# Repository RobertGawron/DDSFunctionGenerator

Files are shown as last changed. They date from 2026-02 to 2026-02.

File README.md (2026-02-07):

# 6MHz DDS Function Generator

**This project is unfinished.**

 

## Summary

A function generator is a laboratory instrument used to generate various electrical waveforms. This project utilizes DDS  [DDS (direct digital synthesis)](https://en.wikipedia.org/wiki/Direct_digital_synthesis), a technique that allows the creation of arbitrary waveforms from a single base frequency.

## Current Version

The current version of the PCB uses components with 0402 (or similar) footprints. Use of these components wasn’t the best choice - they're too difficult to solder, and there was no need to minimize the board size. The next version of the PCB will switch to 0805 components for easier assembly.

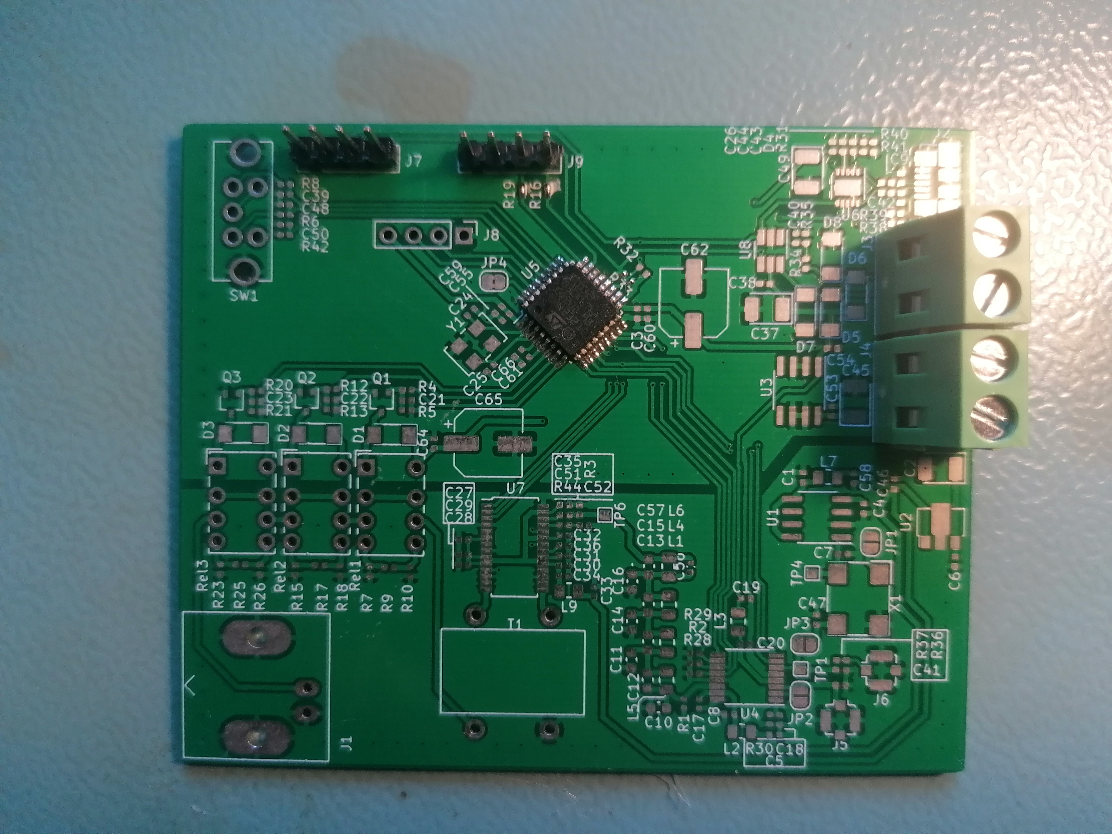
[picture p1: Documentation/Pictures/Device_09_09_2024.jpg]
Photo of the assembled PCB


## System Architecture

System Architecture

Tools: PlantUML

## Hardware

Tools: KiCad (for PCB design).

## Software

Tools:
* **Business Logic:** Written in Forth, a stack-based programming language designed for embedded systems and control applications.
* **Drivers:** Developed in C++17.
* **Hardware Abstraction Layer (HAL):** Auto-generated using CubeMX, a tool from STMicroelectronics.

## Simulation

This project includes an LCD for user interaction. To simplify the creation of the layout, a simulation environment has been developed. 

This simulation combines the following:
* **UI:** Built using PyQt for rendering the LCD layout and facilitating user interaction.
* **Business Logic:** Reuses the core firmware logic directly from the hardware codebase.
* HAL and Driver Mocks: Created in C++.

[More Info](./Simulation/FirmwarePCSimulator/README.md)

## Enclosure

The device's enclosure is designed using **OpenSCAD**, a script-based 3D CAD modeler that allows precise and parametric design.

[More Info](./Mechanic/MechanicOverview/README.md)

## Devops

Repetitive setup tasks are best left to automation, which is why the development environment is managed with Docker. This approach eliminates the need to deal with outdated installation lists or READMEs—just run the container, and everything is ready to go.

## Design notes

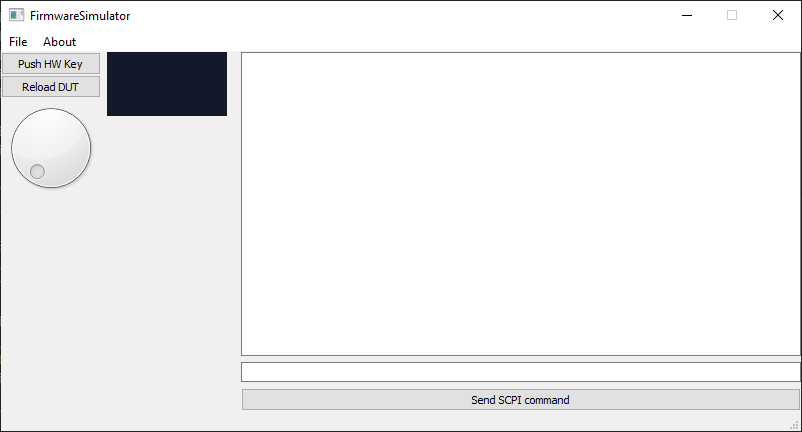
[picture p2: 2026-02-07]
Documentation/Pictures/PCSimulation_20_10_2020.png

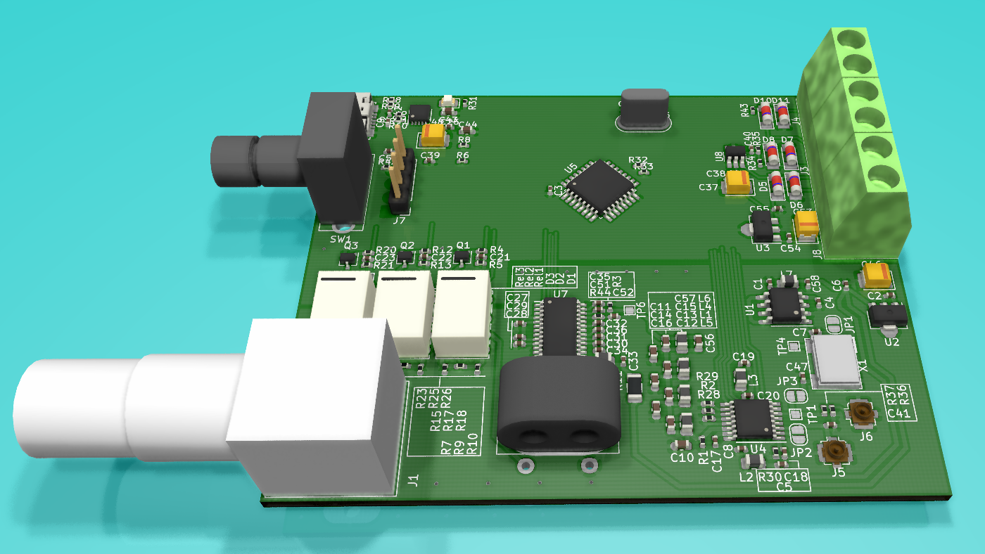
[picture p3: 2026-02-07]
Documentation/Pictures/render_08_12_2019.png

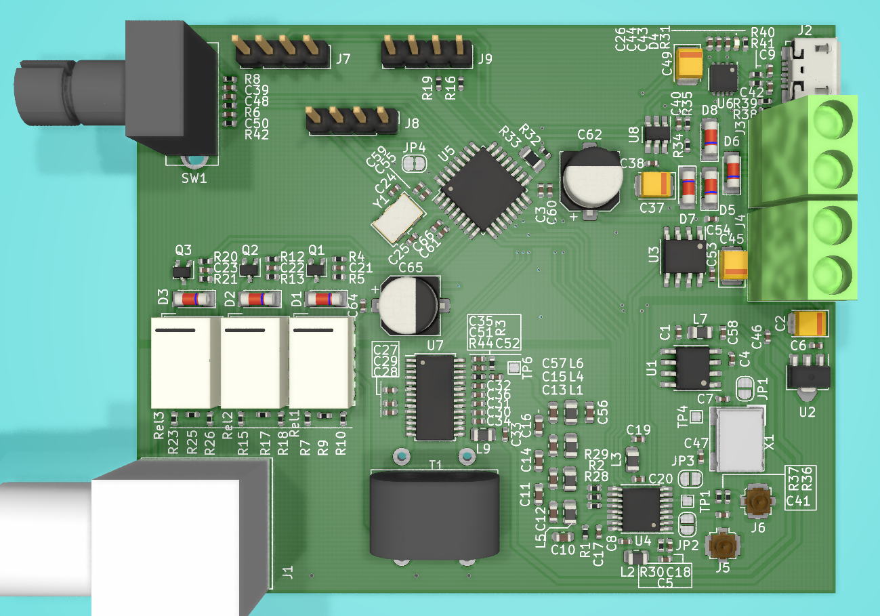
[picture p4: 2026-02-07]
Documentation/Pictures/render_28_12_2019.png

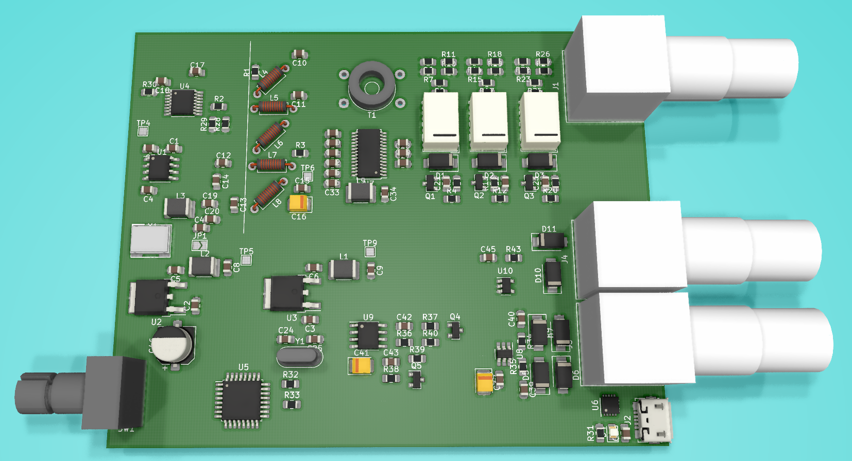
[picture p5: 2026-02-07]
Documentation/Pictures/render_01_11_2019.png

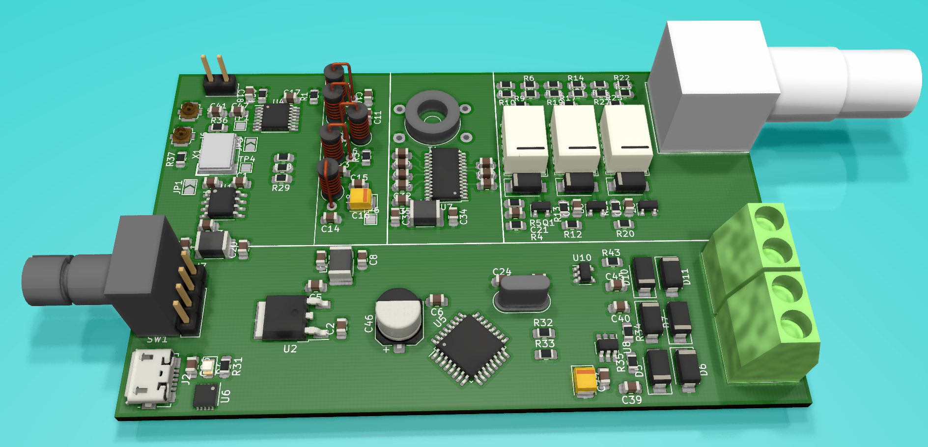
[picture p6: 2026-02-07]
Documentation/Pictures/render_03_11_2019.png

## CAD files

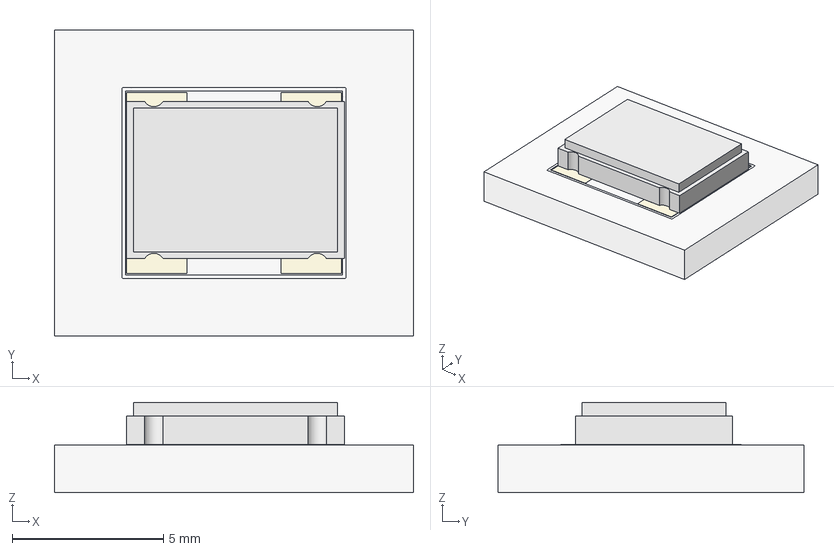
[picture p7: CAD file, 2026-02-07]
Mechanic/KiCADModels/FreeCAD/LF_SPXO018035.FCStd
11.9 x 10.1 x 2.99 mm
FrontSilk
TopPads
Pcb

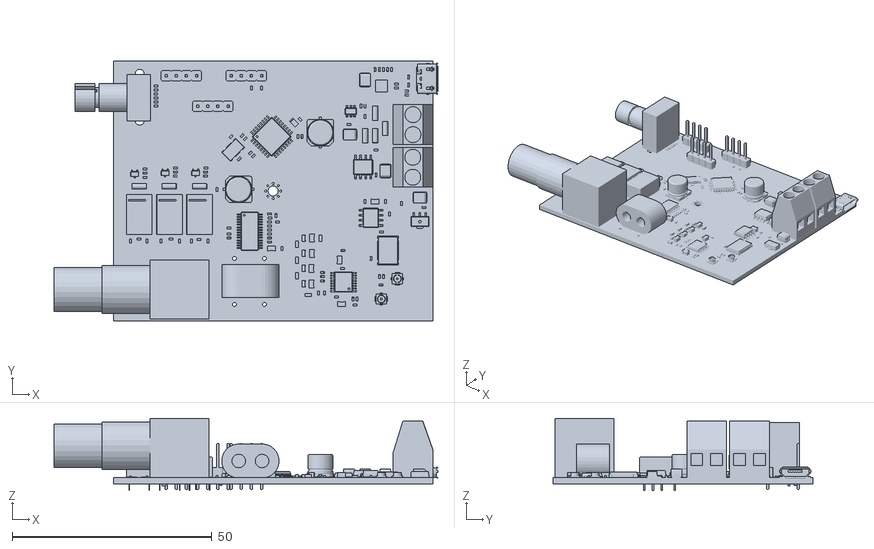
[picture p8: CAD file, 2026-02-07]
Mechanic/MechanicOverview/PCB.stl
96.1 x 65.0 x 18.1

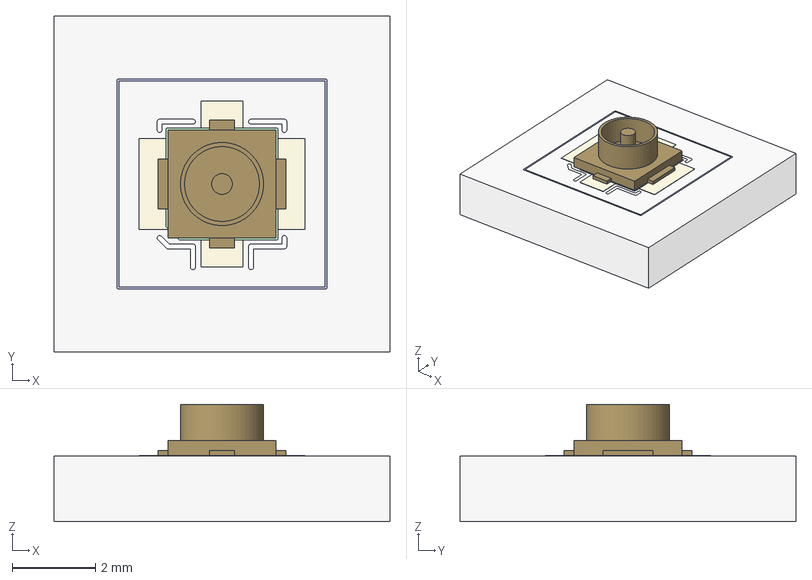
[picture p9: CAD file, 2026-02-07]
Mechanic/KiCADModels/FreeCAD/MOLEX_73412-0110.FCStd
8.08 x 8.08 x 2.82 mm
FCrtYd
FFab
FrontSilk
TopPads
Pcb
LinearExtrude

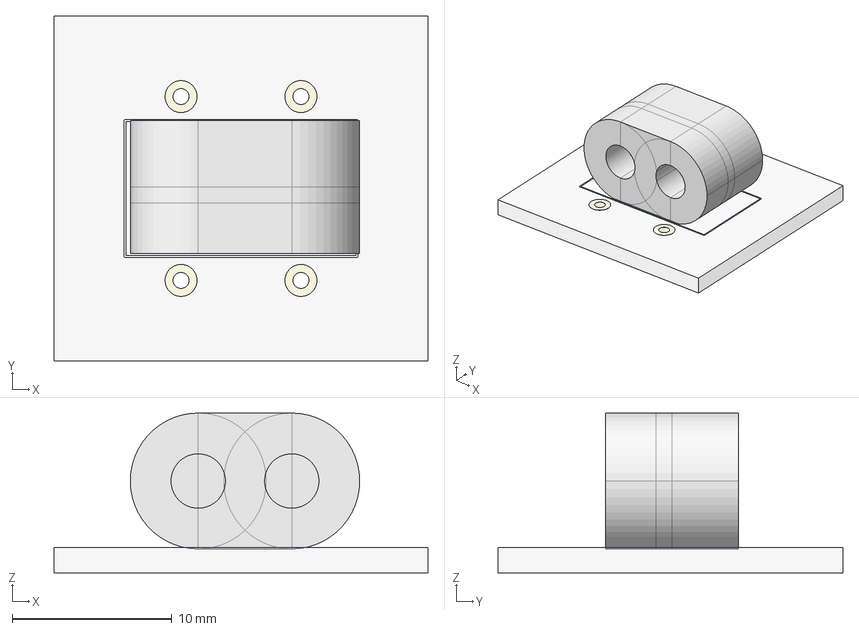
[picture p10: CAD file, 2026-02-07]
Mechanic/KiCADModels/FreeCAD/Transformer_B62152_8.3.FCStd
23.4 x 21.6 x 10.0 mm
FrontSilk
TopPads
BotPads
PTHs
Pcb

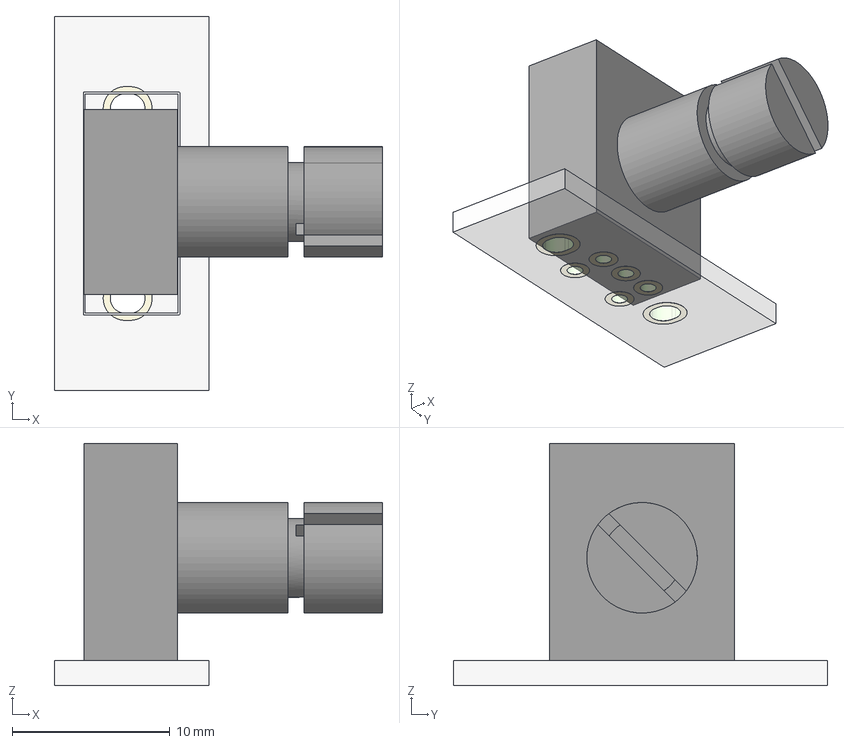
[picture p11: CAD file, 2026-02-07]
Mechanic/KiCADModels/FreeCAD/EN11-VNB1BQ15.FCStd
20.8 x 23.7 x 15.3 mm
FrontSilk
TopPads
BotPads
PTHs
Pcb
Matrix_Union

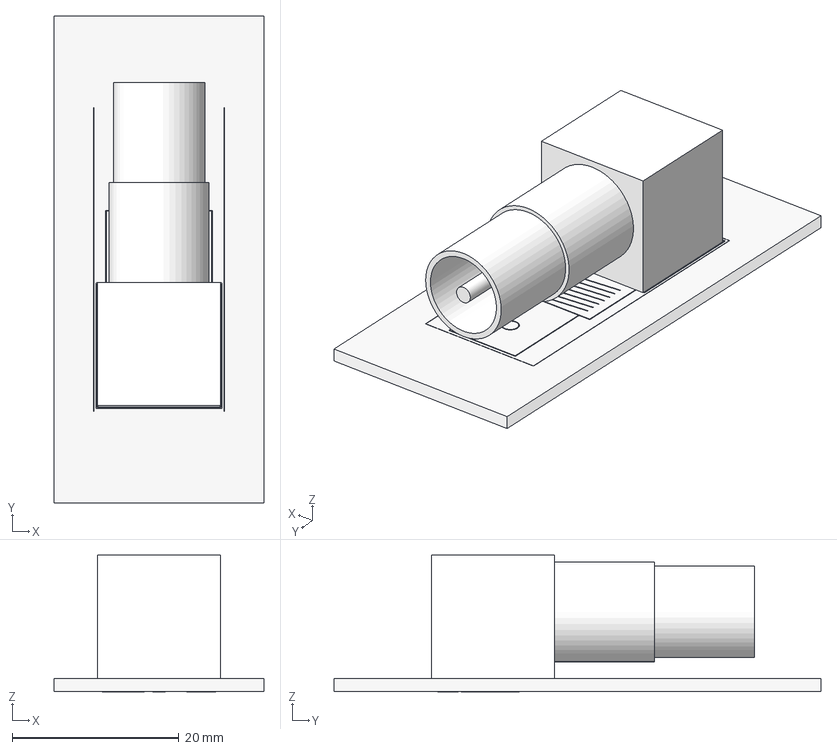
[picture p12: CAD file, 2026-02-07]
Mechanic/KiCADModels/FreeCAD/BNC_Amphenol_B6252HB-NPP3G-50_Horizontal.FCStd
25.2 x 58.5 x 16.4 mm
FCrtYd
FFab
FrontSilk
TopPads
BotPads
PTHs
Pcb

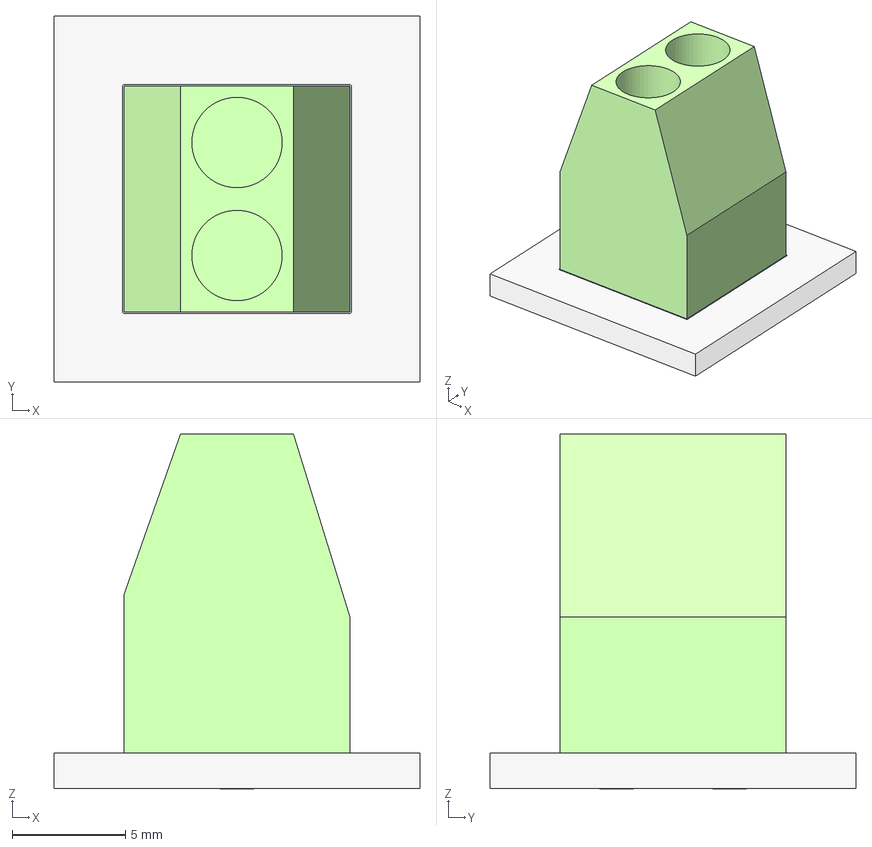
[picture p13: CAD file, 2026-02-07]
Mechanic/KiCADModels/FreeCAD/DG128-5.0-02P-14-00A.FCStd
16.2 x 16.2 x 15.7 mm
FrontSilk
TopPads
BotPads
PTHs
Pcb

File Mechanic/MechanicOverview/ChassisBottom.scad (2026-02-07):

// This is model of bottom chassis.

module ChassisBottom_FrontPanel(Height)
{
    translate([-PCB_X/2 - CHASSIS_THICKNESS-COMPONENT_TOLERANCE,
                -PCB_Y/2,
                Height])
    {
        GenericFrontPanel();
    }
}

module ChassisBottom_SupportAroundPCB()
{
    linear_extrude(height = 2*CHASSIS_THICKNESS+PCB_Z_OFFSET, convexity = 10, twist = 0)
    {
        square([PCB_X+2*COMPONENT_TOLERANCE, CHASSIS_THICKNESS]);
    }
}

module ChassisBottom_SupportsAroundPCB()
{
    translate([-PCB_X/2 -COMPONENT_TOLERANCE,
                -PCB_Y/2-CHASSIS_THICKNESS-COMPONENT_TOLERANCE,
                0])
    {
        ChassisBottom_SupportAroundPCB();
    }

    translate([-PCB_X/2 - COMPONENT_TOLERANCE,
                PCB_Y/2+COMPONENT_TOLERANCE,
                0])
    {
        ChassisBottom_SupportAroundPCB();
    }
}

module ChassisBottom_PCBMountingHole()
{
    translate([0,
                0,
                CHASSIS_THICKNESS])
    {
        GenericChassis_InsertNutSocket(PCB_Z_OFFSET, false);
    }
}

module ChassisBottom_PCBBottomHolder()
{
    PCBBottomHolderThickness = 2;

    linear_extrude(height = PCB_Z_OFFSET, convexity = 10, twist = 0)
    {
        square([PCBBottomHolderThickness, PCB_Y]);
    }
}

module ChassisBottom_PCBBottomHolders()
{
    translate([-PCB_X/2,
                -PCB_Y/2,
                CHASSIS_THICKNESS])
    {
        ChassisBottom_PCBBottomHolder();
    }

    translate([PCB_X/2-1,
                -PCB_Y/2,
                CHASSIS_THICKNESS])
    {
        ChassisBottom_PCBBottomHolder();
    }
}

module ChassisBottom(Height)
{
    difference()
    {
        union()
        {
            GenericChassis(Height);
            ChassisBottom_FrontPanel(Height);
            ChassisBottom_SupportsAroundPCB();
            ChassisBottom_PCBMountingHole();
            ChassisBottom_PCBBottomHolders();

            InsertNutSockets(Height, false);
        }

        // add mounting for top and bottom chassis
        InsertNutSockets(Height, true);

                // add hole for USB socket
        TopHassisUsbYOffset = -2.4; // TODO parametrize it
        translate([PCB_X/2 + COMPONENT_TOLERANCE, 
                    USB_Y,
                    Height + TopHassisUsbYOffset])
        {
            rotate([90,0,90])
            {
                USBConnector();
            }
        }
    }
}

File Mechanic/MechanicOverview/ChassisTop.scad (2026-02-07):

// This is model of top chassis.

// below values are taken from KiCad model

SCREW_CONNECTOR_DX = 10 + COMPONENT_TOLERANCE;
SCREW_CONNECTOR_Y = 1 - COMPONENT_TOLERANCE;
SCREW_CONNECTOR_DY = 20.668 + 2*COMPONENT_TOLERANCE;

AdcPowerSupplyYOffset = PCB_X/2
                        - SCREW_CONNECTOR_DX
                        + CHASSIS_THICKNESS
                        - COMPONENT_TOLERANCE;

module ChassisTop_WallsAroundADCAndPowerSupplySocket(Height)
{
    linear_extrude(height = Height, convexity = 10, twist = 0)
    {
        translate([AdcPowerSupplyYOffset,
                    -SCREW_CONNECTOR_DY - SCREW_CONNECTOR_Y - CHASSIS_THICKNESS,
                    0])
        {
            square([SCREW_CONNECTOR_DX + COMPONENT_TOLERANCE, CHASSIS_THICKNESS]);
        }

        translate([AdcPowerSupplyYOffset,
                    -SCREW_CONNECTOR_DY - SCREW_CONNECTOR_Y + SCREW_CONNECTOR_DY,
                    0])
        {
            square([SCREW_CONNECTOR_DX + COMPONENT_TOLERANCE, CHASSIS_THICKNESS]);
        }

        translate([AdcPowerSupplyYOffset,
                    -SCREW_CONNECTOR_DY - SCREW_CONNECTOR_Y,
                    0])
        {
            square([CHASSIS_THICKNESS, SCREW_CONNECTOR_DY + CHASSIS_THICKNESS]);
        }
    }
}

module ChassisTop_SupportFrontPanel()
{
    translate([-PCB_X/2 -COMPONENT_TOLERANCE,
               -PCB_Y/2,
                CHASSIS_THICKNESS])
    {
        linear_extrude(height = CHASSIS_THICKNESS, convexity = 10, twist = 0)
        {
            square([CHASSIS_THICKNESS, PCB_Y]);
        }
    }

}

module ChassisTop_DebugPanelMountingScrewSupport()
{

    DebugPanelSupportSize = 10;

    translate([-PCB_X/2+DEBUG_CONNECTOR_X+DEBUG_CONNECTOR_DX/2,
            -PCB_Y/2+DEBUG_CONNECTOR_DY/2+COMPONENT_TOLERANCE,
            0])
    {
        difference()
        {
            union()
            {
                translate([0,DebugPanelSupportSize/2,0])
                {
                    linear_extrude(height = CHASSIS_THICKNESS+INSERT_NUT_LENGTH, convexity = 10, twist = 0)
                    {
                        square([INSERT_NUT_HOLDER_DIAMETER, DebugPanelSupportSize], center=true);
                    }
                }
                GenericChassis_InsertNutSocket(CHASSIS_THICKNESS+INSERT_NUT_LENGTH, false);
            }

            // add hole for debug socket screw
            linear_extrude(height = CHASSIS_THICKNESS+INSERT_NUT_LENGTH, convexity = 10, twist = 0)
            {
                circle(r=INSERT_NUT_RADIUS);
            }
        }
    }
}

module Chassis3DTop(Height)
{
    difference()
    {
        union()
        {
            difference()
            {
                GenericChassis(Height);
                GenericDebugPanel(Height);
            }

            ChassisTop_DebugPanelMountingScrewSupport();
        }

        // add hole for ADC and power supply socket
        translate([AdcPowerSupplyYOffset,
                    -SCREW_CONNECTOR_DY - SCREW_CONNECTOR_Y,
                    0])
        {
            linear_extrude(height = Height, convexity = 10, twist = 0)
            {
                square([SCREW_CONNECTOR_DX + CHASSIS_THICKNESS, SCREW_CONNECTOR_DY]);
            }
        }

        // add hole for front pannel
        translate([-PCB_X/2 - CHASSIS_THICKNESS-COMPONENT_TOLERANCE,
                   -PCB_Y/2,
                    CHASSIS_THICKNESS])
        {
            GenericFrontPanel();
        }

        // add hole for USB socket
        TopHassisUsbYOffset = -0.85; // TODO parametrize it
        translate([PCB_X/2 + COMPONENT_TOLERANCE,
                    -USB_Y-USB_LENGTH,
                    Height + TopHassisUsbYOffset])
        {
            rotate([90,0,90])
            {
                USBConnector();
            }
        }
    }

    ChassisTop_WallsAroundADCAndPowerSupplySocket(Height);
    ChassisTop_SupportFrontPanel();

    // add nounting screws
    InsertNutSockets(Height, false);




    
}

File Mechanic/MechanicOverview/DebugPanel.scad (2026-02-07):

// This is model panel for UART and MCU sockets, it will be taken out for debugging and development.

module GenericDebugPanel(Height)
{
    translate([-PCB_X/2+DEBUG_CONNECTOR_X,
                ,-PCB_Y/2
                    + COMPONENT_TOLERANCE
                    - 2*CHASSIS_THICKNESS // TODO this is wrong
                    - DEBUG_CONNECTOR_DY/2
                    + CHASSIS_CORNER_DIAMETER,
                0])
    {
        linear_extrude(height = Height, convexity = 10, twist = 0)
        {
            square([DEBUG_CONNECTOR_DX, DEBUG_CONNECTOR_DY]);
        }
    }
}

module DebugPanel(Height)
{
    difference()
    {
        GenericChassis(Height);

        difference()
        {
            GenericChassis(Height);
            GenericDebugPanel(Height);
        }
    }
}

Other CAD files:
Mechanic/MechanicOverview/GenericChassis.scad
Mechanic/KiCADModels/FreeCAD/MOLEX_73412-0110.scad
Mechanic/KiCADModels/OpenSCAD/BNC_Amphenol_B6252HB-NPP3G-50_Horizontal.scad
Mechanic/KiCADModels/OpenSCAD/DG128-5.0-02P-14-00A.scad
Mechanic/KiCADModels/OpenSCAD/EN11-VNB1BQ15.scad
Mechanic/KiCADModels/OpenSCAD/LF_SPXO018035.scad
Mechanic/KiCADModels/OpenSCAD/Transformer_B62152_8.3.scad
Mechanic/MechanicOverview/GenericFrontPanel.scad
Mechanic/MechanicOverview/MechanicOverview.scad
Mechanic/MechanicOverview/USBConnector.scad

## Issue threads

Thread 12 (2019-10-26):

Update README.md for render of PCB.

RobertGawron, 2019-10-26:

RobertGawron, 2019-11-01:
Fixed by 70bd080a7f343182590361790dcc85e7a82861be

Closed 2019-11-01.

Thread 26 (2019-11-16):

Check order of pin 2 and 3 on the USB socket

RobertGawron, 2019-11-16:
What is the order on the socked I have? Needed to avoid rework after assembly.

RobertGawron, 2021-07-17:
done

Closed 2021-07-17.

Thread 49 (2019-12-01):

Check bottom/top layer correctness before ordering PCB

RobertGawron, 2019-12-01:

RobertGawron, 2021-07-17:
done

Closed 2021-07-17.

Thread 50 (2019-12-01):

Add 3D model of enclosure

RobertGawron, 2019-12-01:

RobertGawron, 2020-12-08:
Missing parts :
- PCB support,
- holes to mount PCB
- fix screw support for top part
- add hole for BNC, encoder and LCD
- finish debug connector
- add USB slot

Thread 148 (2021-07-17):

Fix USB footprint

RobertGawron, 2021-07-17:

RobertGawron, 2021-10-02:
USB from Raspberry will be used.

Closed 2021-10-02.

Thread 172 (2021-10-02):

Replace fancy encoder by 4 buttons

RobertGawron, 2021-10-02:

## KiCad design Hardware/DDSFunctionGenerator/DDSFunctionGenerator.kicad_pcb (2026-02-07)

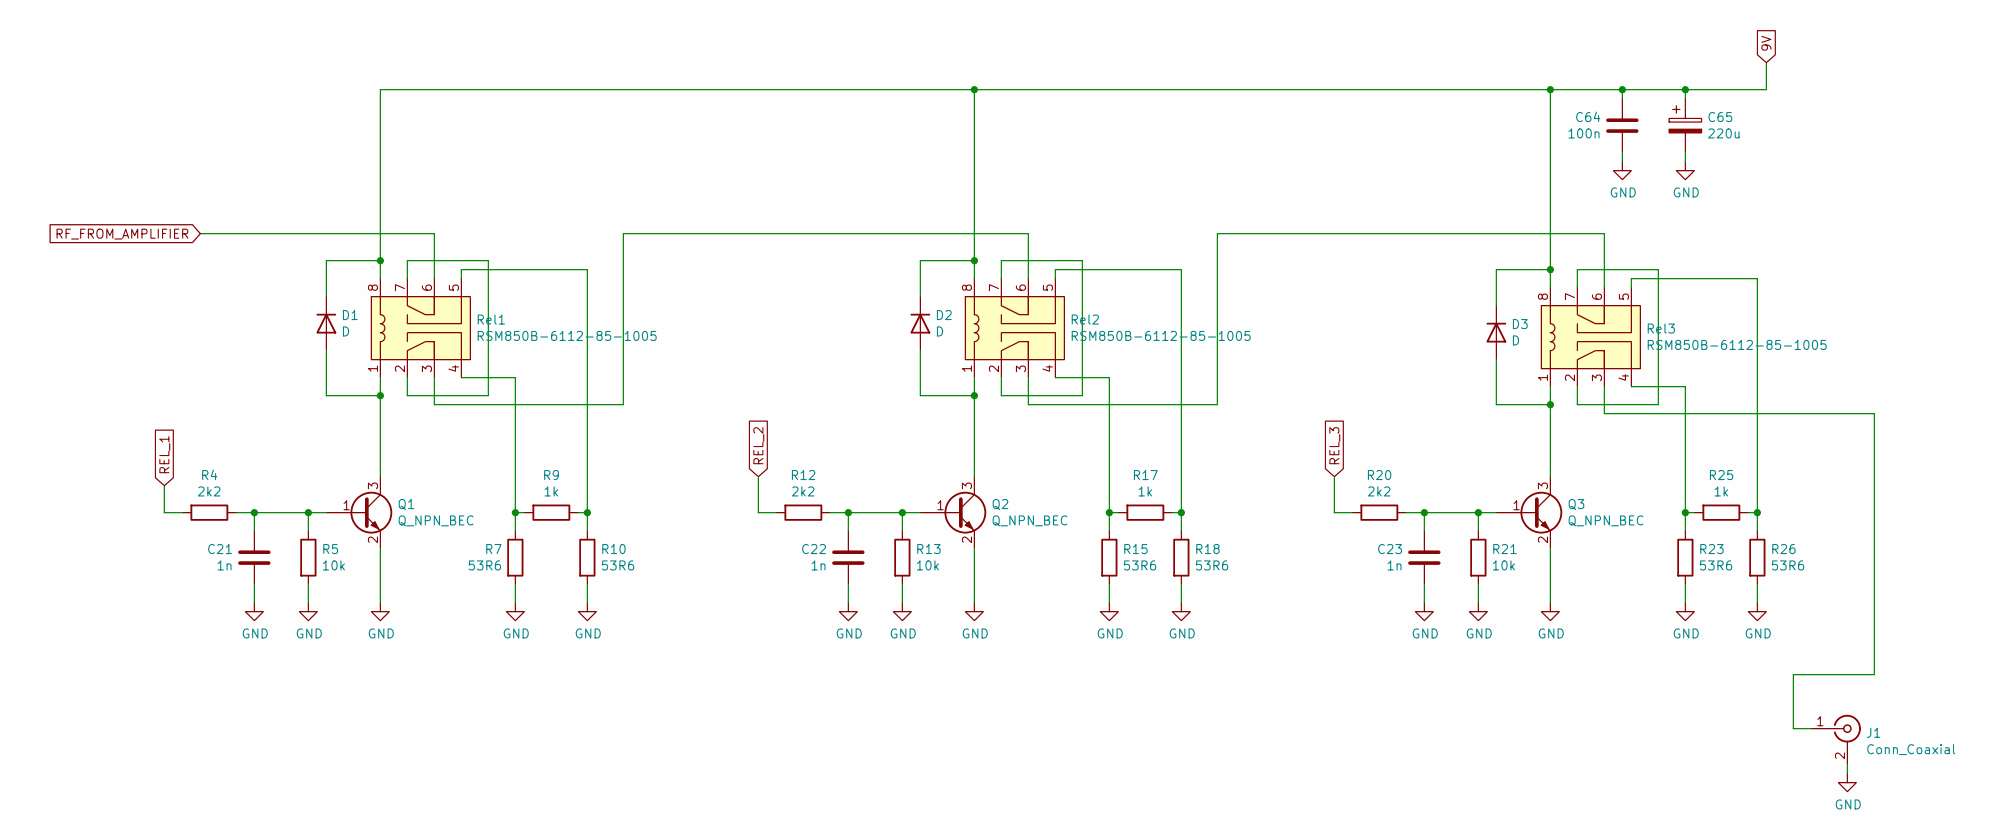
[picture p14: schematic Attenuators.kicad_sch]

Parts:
C21, C22, C23: 1n; C_0402_1005Metric
C64: 100n; C_0402_1005Metric
C65: 220u; CP_Elec_6.3x5.8
D1, D2, D3: D; D_MiniMELF
J1: Conn_Coaxial; BNC_Amphenol_B6252HB-NPP3G-50_Horizontal
Q1, Q2, Q3: Q_NPN_BEC; SOT-323_SC-70
R4, R12, R20: 2k2; R_0402_1005Metric
R5, R13, R21: 10k; R_0402_1005Metric
R7, R10, R15, R18, R23, R26: 53R6; R_0402_1005Metric
R9, R17, R25: 1k; R_0402_1005Metric
Rel1, Rel2, Rel3: RSM850B-6112-85-1005; Relay_DPDT_Omron_G6K-2P-Y

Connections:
9V: C64.1, C65.1, D1.1 (K), D2.1 (K), D3.1 (K), Rel1.8, Rel2.8, Rel3.8; also elsewhere on the board
GND: C21.2, C22.2, C23.2, C64.2, C65.2, J1.2 (Ext), Q1.2 (E), Q2.2 (E), Q3.2 (E), R5.2, R7.2, R10.2, R13.2, R15.2, R18.2, R21.2, R23.2, R26.2; also elsewhere on the board
unnamed: C21.1, Q1.1 (B), R4.1, R5.1
unnamed: C22.1, Q2.1 (B), R12.1, R13.1
unnamed: C23.1, Q3.1 (B), R20.1, R21.1
unnamed: D1.2 (A), Q1.3 (C), Rel1.1
unnamed: D2.2 (A), Q2.3 (C), Rel2.1
unnamed: D3.2 (A), Q3.3 (C), Rel3.1
unnamed: J1.1 (In), Rel3.3
unnamed: R7.1, R9.2, Rel1.4
unnamed: R9.1, R10.1, Rel1.5
unnamed: R15.1, R17.2, Rel2.4
unnamed: R17.1, R18.1, Rel2.5
unnamed: R23.1, R25.2, Rel3.4
unnamed: R25.1, R26.1, Rel3.5
unnamed: Rel1.2, Rel1.7
unnamed: Rel1.3, Rel2.6
unnamed: Rel2.2, Rel2.7
unnamed: Rel2.3, Rel3.6
unnamed: Rel3.2, Rel3.7
REL_1: R4.2; also elsewhere on the board
REL_2: R12.2; also elsewhere on the board
REL_3: R20.2; also elsewhere on the board
RF_FROM_AMPLIFIER: Rel1.6; also elsewhere on the board

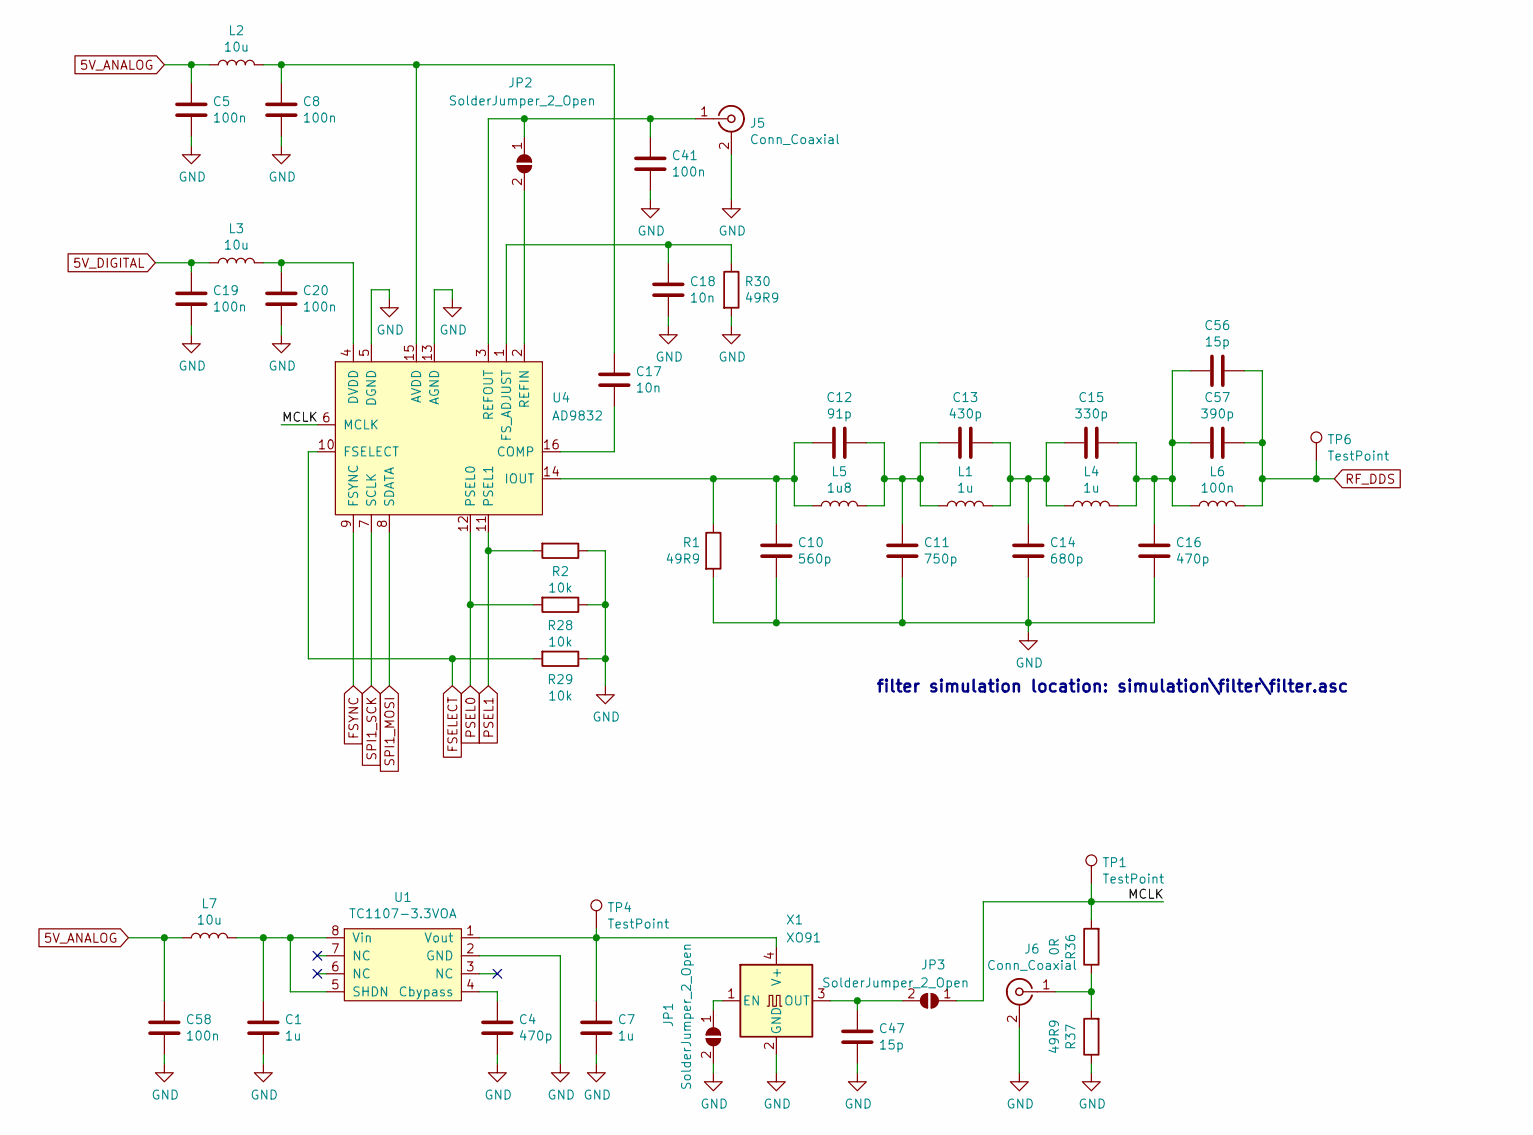
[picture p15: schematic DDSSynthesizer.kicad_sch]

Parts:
C1, C7: 1u; C_0402_1005Metric
C4: 470p; C_0402_1005Metric
C5, C8, C19, C20, C41, C58: 100n; C_0402_1005Metric
C10: 560p; C_0603_1608Metric
C11: 750p; C_0603_1608Metric
C12: 91p; C_0603_1608Metric
C13: 430p; C_0603_1608Metric
C14: 680p; C_0603_1608Metric
C15: 330p; C_0603_1608Metric
C16: 470p; C_0603_1608Metric
C17, C18: 10n; C_0402_1005Metric
C47, C56: 15p; C_0402_1005Metric
C57: 390p; C_0603_1608Metric
J5, J6: Conn_Coaxial; U.FL_Molex_MCRF_73412-0110_Vertical
JP1, JP2, JP3: SolderJumper_2_Open; SolderJumper-2_P1.3mm_Open_RoundedPad1.0x1.5mm
L1, L4: 1u; L_0805_2012Metric
L2, L3, L7: 10u; L_0805_2012Metric
L5: 1u8; L_0805_2012Metric
L6: 100n; L_0805_2012Metric
R1, R30, R37: 49R9; R_0402_1005Metric
R2, R28, R29: 10k; R_0402_1005Metric
R36: 0R; R_0402_1005Metric
TP1, TP4, TP6: TestPoint; TestPoint_Pad_1.0x1.0mm
U1: TC1107-3.3VOA; SOIC-8_3.9x4.9mm_P1.27mm
U4: AD9832; TSSOP-16_4.4x5mm_P0.65mm
X1: XO91; LF_SPXO018035

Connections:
5V_ANALOG: C5.1, C58.1, L2.1, L7.1; also elsewhere on the board
5V_DIGITAL: C19.1, L3.1; also elsewhere on the board
/DDSSynthesizer/MCLK: JP3.1 (A), R36.2, TP1.1, U4.6 (MCLK)
FSELECT: R29.2, U4.10 (FSELECT); also elsewhere on the board
FSYNC: U4.9 (FSYNC); also elsewhere on the board
GND: C1.1, C4.1, C5.2, C7.1, C8.2, C10.1, C11.1, C14.1, C16.1, C18.2, C19.2, C20.2, C41.2, C47.1, C58.2, J5.2 (Ext), J6.2 (Ext), JP1.2 (B), R1.2, R2.1, R28.1, R29.1, R30.2, R37.1, U1.2 (GND), U4.5 (DGND), U4.13 (AGND), X1.2 (GND); also elsewhere on the board
unnamed: C1.2, L7.2, U1.5 (SHDN), U1.8 (Vin)
unnamed: C4.2, U1.4 (Cbypass)
unnamed: C7.2, TP4.1, U1.1 (Vout), X1.4 (V+)
unnamed: C10.2, C12.1, L5.1, R1.1, U4.14 (IOUT)
unnamed: C11.2, C12.2, C13.1, L1.1, L5.2
unnamed: C13.2, C14.2, C15.1, L1.2, L4.1
unnamed: C15.2, C16.2, C56.1, C57.1, L4.2, L6.1
unnamed: C8.1, C17.1, L2.2, U4.15 (AVDD)
unnamed: C17.2, U4.16 (COMP)
unnamed: C18.1, R30.1, U4.1 (FS_ADJUST)
unnamed: C20.1, L3.2, U4.4 (DVDD)
unnamed: C41.1, J5.1 (In), JP2.1 (A), U4.3 (REFOUT)
unnamed: C47.2, JP3.2 (B), X1.3 (OUT)
unnamed: J6.1 (In), R36.1, R37.2
unnamed: JP1.1 (A), X1.1 (EN)
unnamed: JP2.2 (B), U4.2 (REFIN)
PSEL0: R28.2, U4.12 (PSEL0); also elsewhere on the board
PSEL1: R2.2, U4.11 (PSEL1); also elsewhere on the board
RF_DDS: C56.2, C57.2, L6.2, TP6.1; also elsewhere on the board
SPI1_MOSI: U4.8 (SDATA); also elsewhere on the board
SPI1_SCK: U4.7 (SCLK); also elsewhere on the board

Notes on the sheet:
filter simulation location: simulation\filter\filter.asc

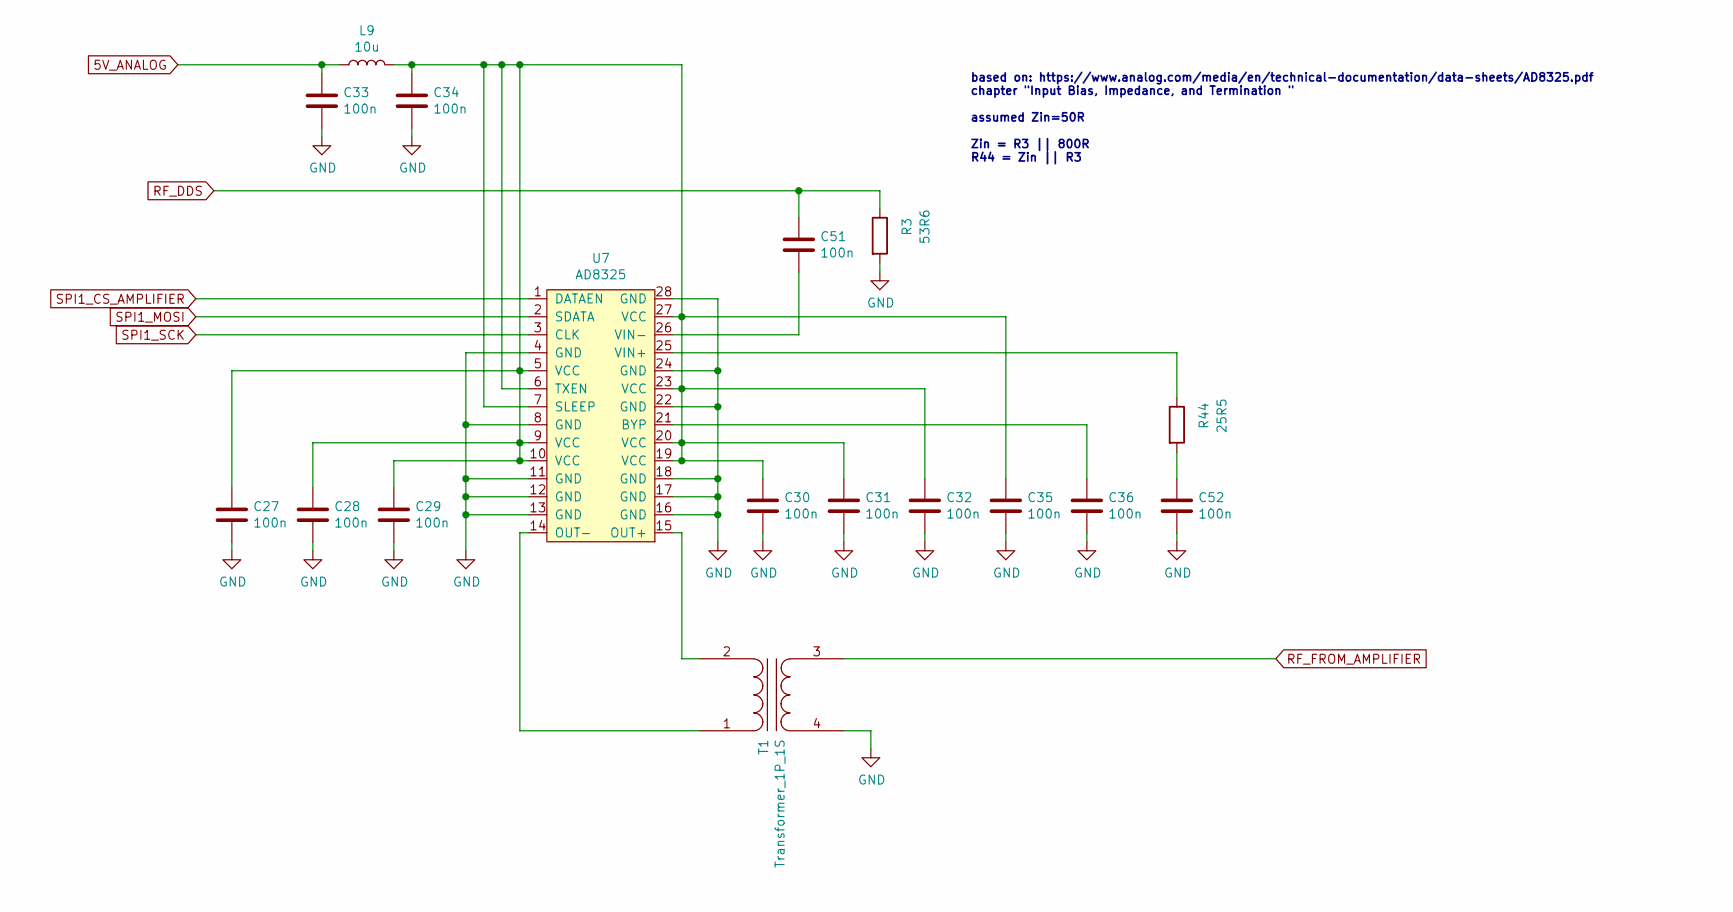
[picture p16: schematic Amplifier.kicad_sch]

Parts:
C27, C28, C29, C30, C31, C32, C33, C34, C35, C36, C51, C52: 100n; C_0402_1005Metric
L9: 10u; L_0805_2012Metric
R3: 53R6; R_0402_1005Metric
R44: 25R5; R_0402_1005Metric
T1: Transformer_1P_1S; Transformer_B62152_8.3
U7: AD8325; TSSOP-28_4.4x9.7mm_P0.65mm

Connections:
5V_ANALOG: C33.1, L9.1; also elsewhere on the board
GND: C27.2, C28.2, C29.1, C30.2, C31.2, C32.2, C33.2, C34.2, C35.2, C36.2, C52.2, R3.2, T1.4 (SB), U7.4 (GND), U7.8 (GND), U7.11 (GND), U7.12 (GND), U7.13 (GND), U7.16 (GND), U7.17 (GND), U7.18 (GND), U7.22 (GND), U7.24 (GND), U7.28 (GND); also elsewhere on the board
unnamed: C27.1, C28.1, C29.2, C30.1, C31.1, C32.1, C34.1, C35.1, L9.2, U7.5 (VCC), U7.6 (TXEN), U7.7 (SLEEP), U7.9 (VCC), U7.10 (VCC), U7.19 (VCC), U7.20 (VCC), U7.23 (VCC), U7.27 (VCC)
unnamed: C36.1, U7.21 (BYP)
unnamed: C51.2, U7.26 (VIN-)
unnamed: C52.1, R44.2
unnamed: R44.1, U7.25 (VIN+)
unnamed: T1.1 (AA), U7.14 (OUT-)
unnamed: T1.2 (AB), U7.15 (OUT+)
RF_DDS: C51.1, R3.1; also elsewhere on the board
RF_FROM_AMPLIFIER: T1.3 (SA); also elsewhere on the board
SPI1_CS_AMPLIFIER: U7.1 (DATAEN); also elsewhere on the board
SPI1_MOSI: U7.2 (SDATA); also elsewhere on the board
SPI1_SCK: U7.3 (CLK); also elsewhere on the board

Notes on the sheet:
based on: https://www.analog.com/media/en/technical-documentation/data-sheets/AD8325.pdf chapter "Input Bias, Impedance, and Termination " assumed Zin=50R Zin = R3 || 800R R44 = Zin || R3

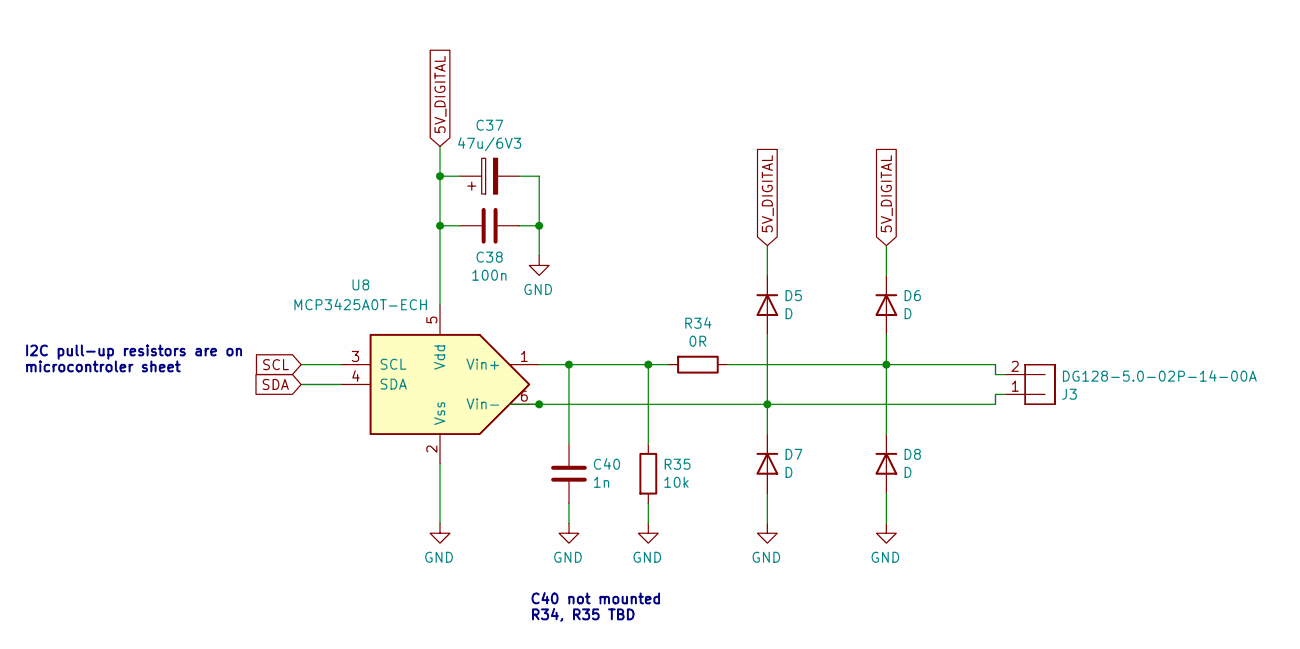
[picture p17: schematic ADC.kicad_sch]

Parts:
C37: 47u/6V3; CP_EIA-3528-21_Kemet-B
C38: 100n; C_0402_1005Metric
C40: 1n; C_0402_1005Metric
D5, D6, D7, D8: D; D_MiniMELF
J3: DG128-5.0-02P-14-00A
R34: 0R; R_0402_1005Metric
R35: 10k; R_0402_1005Metric
U8: MCP3425A0T-ECH; SOT-23-6_Handsoldering

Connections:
5V_DIGITAL: C37.1, C38.2, D5.1 (K), D6.1 (K), U8.5 (Vdd); also elsewhere on the board
GND: C37.2, C38.1, C40.2, D7.2 (A), D8.2 (A), R35.2, U8.2 (Vss); also elsewhere on the board
unnamed: C40.1, R34.2, R35.1, U8.1 (Vin+)
unnamed: D5.2 (A), D7.1 (K), J3.1, U8.6 (Vin-)
unnamed: D6.2 (A), D8.1 (K), J3.2, R34.1
SCL: U8.3 (SCL); also elsewhere on the board
SDA: U8.4 (SDA); also elsewhere on the board

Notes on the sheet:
I2C pull-up resistors are on microcontroler sheet
C40 not mounted R34, R35 TBD

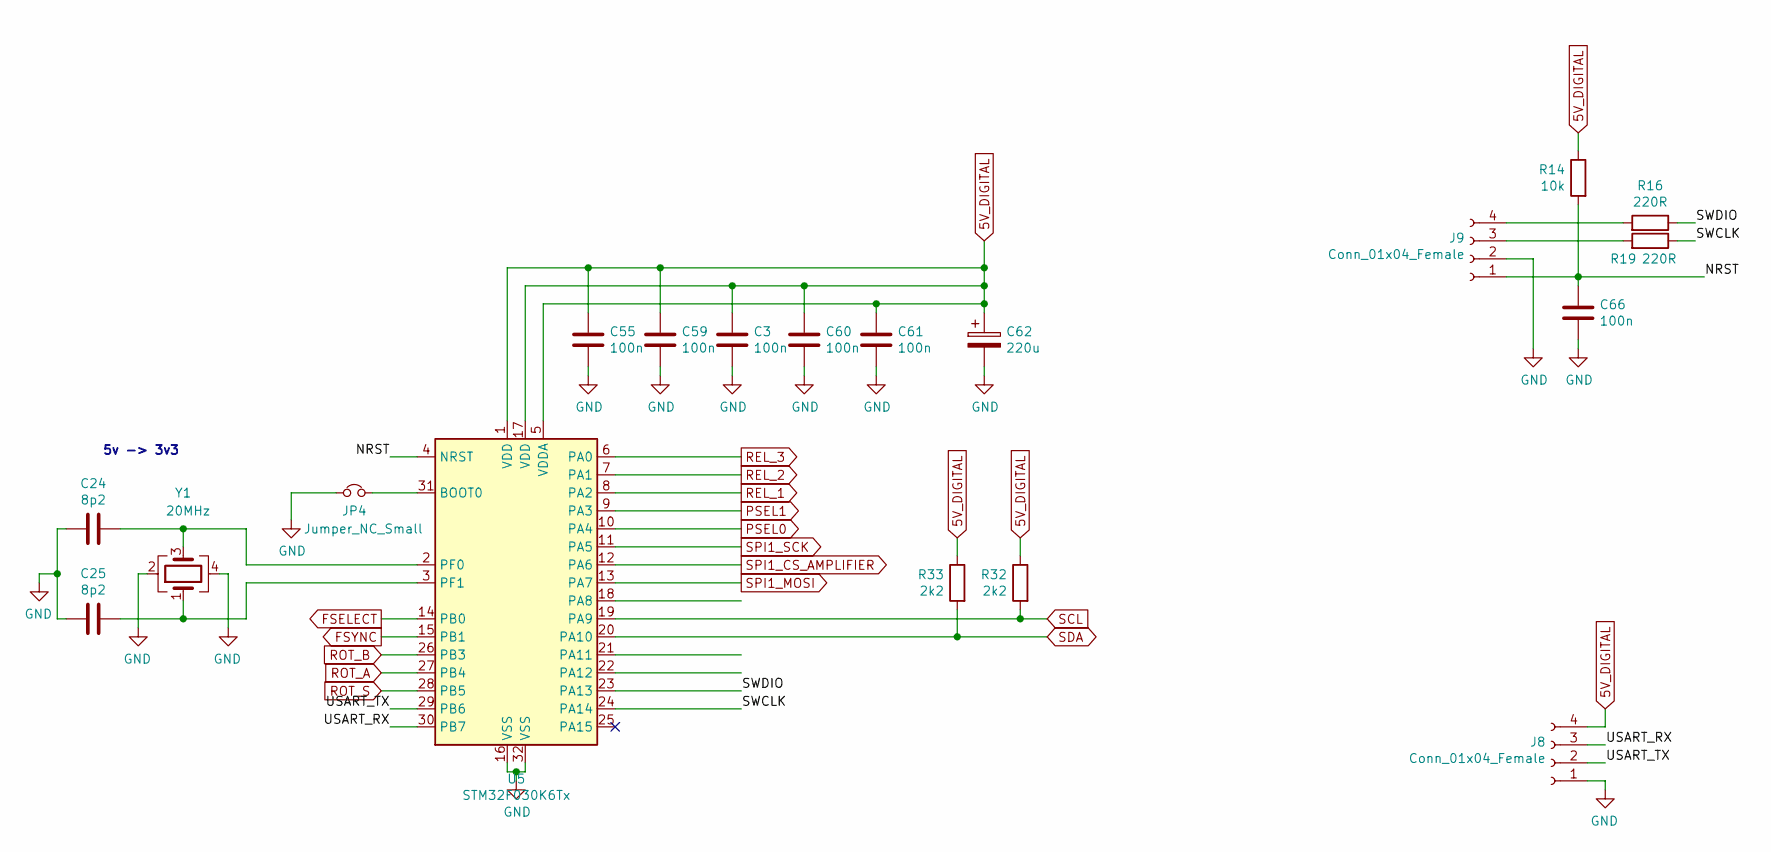
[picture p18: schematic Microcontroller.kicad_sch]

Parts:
C3, C55, C59, C60, C61, C66: 100n; C_0402_1005Metric
C24, C25: 8p2; C_0402_1005Metric
C62: 220u; CP_Elec_6.3x5.8
J8, J9: Conn_01x04_Female; PinHeader_1x04_P2.54mm_Vertical
JP4: Jumper_NC_Small; SolderJumper-2_P1.3mm_Bridged2Bar_RoundedPad1.0x1.5mm
R14: 10k; R_0402_1005Metric
R16, R19: 220R; R_0402_1005Metric
R32, R33: 2k2; R_0402_1005Metric
U5: STM32F030K6Tx; LQFP-32_7x7mm_P0.8mm
Y1: 20MHz; Oscillator_SMD_EuroQuartz_XO53-4Pin_5.0x3.2mm

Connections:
5V_DIGITAL: C3.1, C55.1, C59.1, C60.1, C61.1, C62.1, J8.4, R14.1, R32.1, R33.1, U5.1 (VDD), U5.5 (VDDA), U5.17 (VDD); also elsewhere on the board
/Microcontroller/NRST: C66.1, J9.1, R14.2, U5.4 (NRST)
/Microcontroller/SWCLK: R19.1, U5.24 (PA14)
/Microcontroller/SWDIO: R16.1, U5.23 (PA13)
/Microcontroller/USART_RX: J8.3, U5.30 (PB7)
/Microcontroller/USART_TX: J8.2, U5.29 (PB6)
FSELECT: U5.14 (PB0); also elsewhere on the board
FSYNC: U5.15 (PB1); also elsewhere on the board
GND: C3.2, C24.1, C25.1, C55.2, C59.2, C60.2, C61.2, C62.2, C66.2, J8.1, J9.2, JP4.1, U5.16 (VSS), U5.32 (VSS), Y1.2, Y1.4; also elsewhere on the board
unnamed: C24.2, U5.2 (PF0), Y1.3
unnamed: C25.2, U5.3 (PF1), Y1.1
unnamed: J9.3, R19.2
unnamed: J9.4, R16.2
unnamed: JP4.2, U5.31 (BOOT0)
PSEL0: U5.10 (PA4); also elsewhere on the board
PSEL1: U5.9 (PA3); also elsewhere on the board
REL_1: U5.8 (PA2); also elsewhere on the board
REL_2: U5.7 (PA1); also elsewhere on the board
REL_3: U5.6 (PA0); also elsewhere on the board
ROT_A: U5.26 (PB3), U5.27 (PB4); also elsewhere on the board
ROT_S: U5.28 (PB5); also elsewhere on the board
SCL: R32.2, U5.19 (PA9); also elsewhere on the board
SDA: R33.2, U5.20 (PA10); also elsewhere on the board
SPI1_CS_AMPLIFIER: U5.12 (PA6); also elsewhere on the board
SPI1_MOSI: U5.13 (PA7); also elsewhere on the board
SPI1_SCK: U5.11 (PA5); also elsewhere on the board

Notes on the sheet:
5v -> 3v3

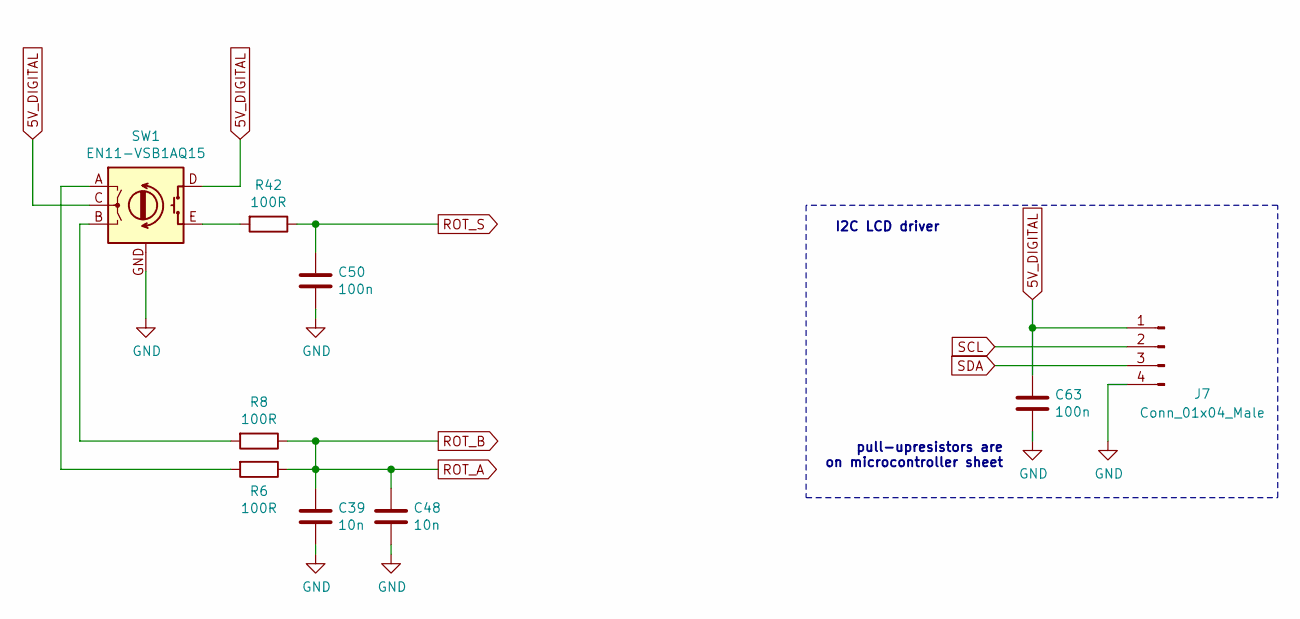
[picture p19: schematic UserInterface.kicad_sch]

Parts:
C39, C48: 10n; C_0402_1005Metric
C50, C63: 100n; C_0402_1005Metric
J7: Conn_01x04_Male; PinHeader_1x04_P2.54mm_Vertical
R6, R8, R42: 100R; R_0402_1005Metric
SW1: EN11-VSB1AQ15; EN11-VNB1BQ15

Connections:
5V_DIGITAL: C63.1, J7.1, SW1.C, SW1.D; also elsewhere on the board
GND: C39.2, C48.2, C50.2, C63.2, J7.4, SW1.GND; also elsewhere on the board
unnamed: R6.2, SW1.A
unnamed: R8.2, SW1.B
unnamed: R42.2, SW1.E
ROT_A: C39.1, C48.1, R6.1, R8.1; also elsewhere on the board
ROT_S: C50.1, R42.1; also elsewhere on the board
SCL: J7.2; also elsewhere on the board
SDA: J7.3; also elsewhere on the board

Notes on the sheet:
pull-upresistors are on microcontroller sheet
I2C LCD driver

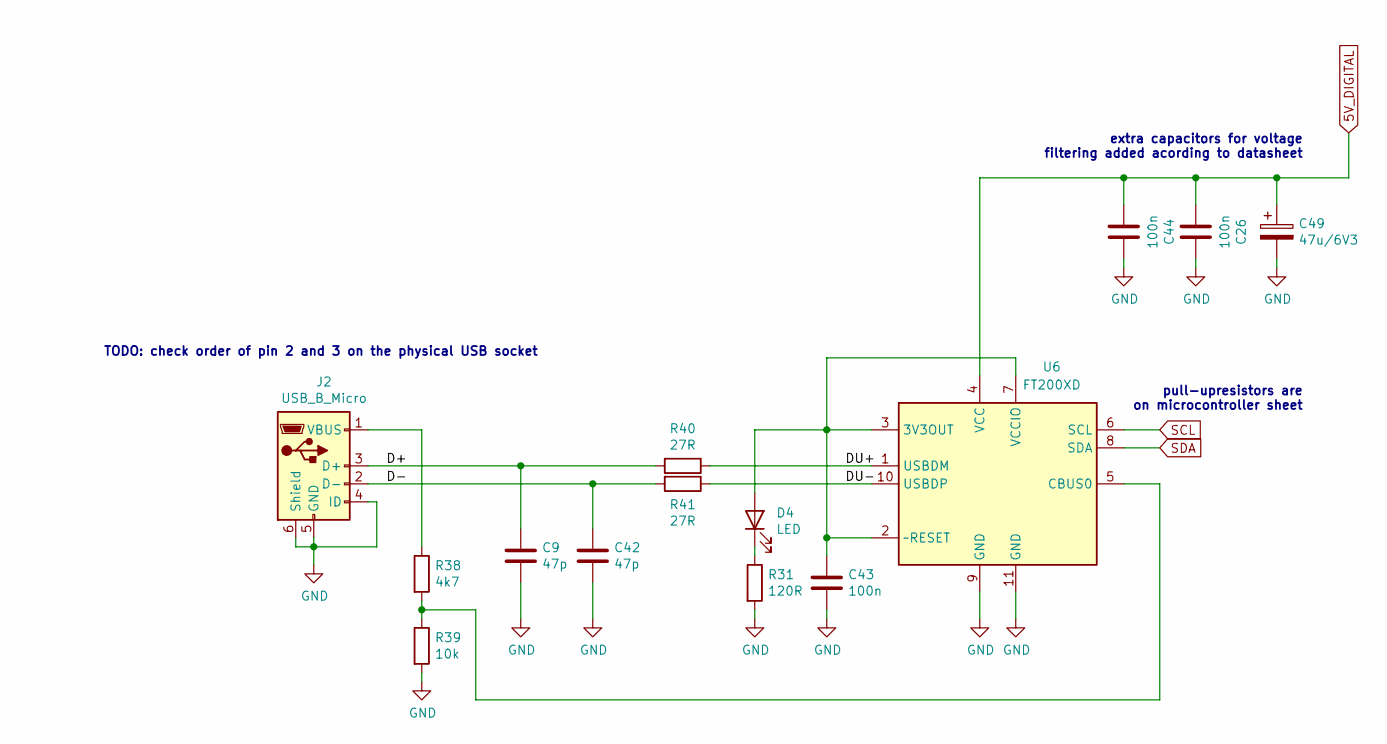
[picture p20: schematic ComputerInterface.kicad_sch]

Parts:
C9, C42: 47p; C_0402_1005Metric
C26, C43, C44: 100n; C_0402_1005Metric
C49: 47u/6V3; CP_EIA-3528-21_Kemet-B
D4: LED; LED_0402_1005Metric
J2: USB_B_Micro; USB_Micro-B_Molex_47346-0001
R31: 120R; R_0402_1005Metric
R38: 4k7; R_0402_1005Metric
R39: 10k; R_0402_1005Metric
R40, R41: 27R; R_0402_1005Metric
U6: FT200XD; DFN-10-1EP_3x3mm_P0.5mm_EP1.55x2.48mm

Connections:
5V_DIGITAL: C26.1, C44.1, C49.1, U6.4 (VCC); also elsewhere on the board
/ComputerInterface/D+: C9.2, J2.3 (D+), R40.2
/ComputerInterface/D-: C42.2, J2.2 (D-), R41.2
/ComputerInterface/DU+: R40.1, U6.1 (USBDM)
/ComputerInterface/DU-: R41.1, U6.10 (USBDP)
GND: C9.1, C26.2, C42.1, C43.1, C44.2, C49.2, J2.4 (ID), J2.5 (GND), J2.6 (Shield), R31.2, R39.2, U6.9 (GND), U6.11 (GND); also elsewhere on the board
unnamed: C43.2, D4.2 (A), U6.2 (~RESET), U6.3 (3V3OUT), U6.7 (VCCIO)
unnamed: D4.1 (K), R31.1
unnamed: J2.1 (VBUS), R38.1
unnamed: R38.2, R39.1, U6.5 (CBUS0)
SCL: U6.6 (SCL); also elsewhere on the board
SDA: U6.8 (SDA); also elsewhere on the board

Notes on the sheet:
extra capacitors for voltage filtering added acording to datasheet
TODO: check order of pin 2 and 3 on the physical USB socket
pull-upresistors are on microcontroller sheet

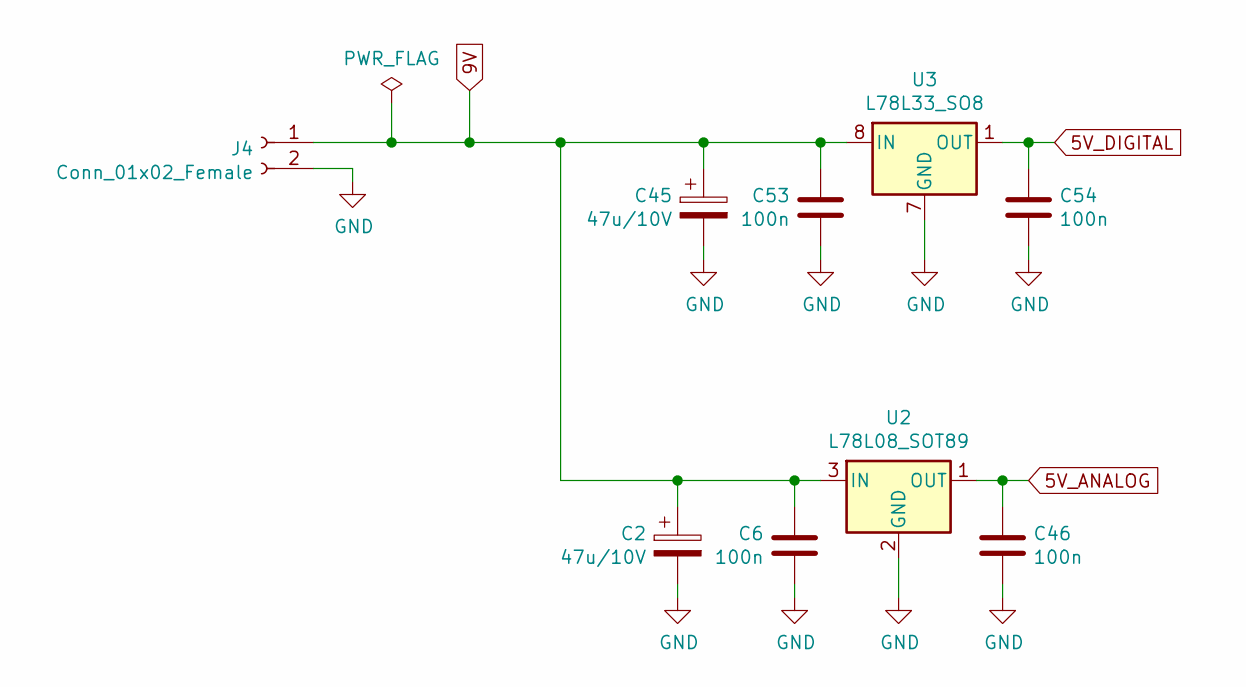
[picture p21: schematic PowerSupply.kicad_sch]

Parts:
C2, C45: 47u/10V; CP_EIA-3528-21_Kemet-B
C6, C46, C53, C54: 100n; C_0402_1005Metric
J4: Conn_01x02_Female; DG128-5.0-02P-14-00A
U2: L78L08_SOT89; SOT-89-3
U3: L78L33_SO8; SOIC-8_3.9x4.9mm_P1.27mm

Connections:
5V_ANALOG: C46.1, U2.1 (OUT); also elsewhere on the board
5V_DIGITAL: C54.1, U3.1 (OUT); also elsewhere on the board
9V: C2.1, C6.1, C45.1, C53.1, J4.1, U2.3 (IN), U3.8 (IN); also elsewhere on the board
GND: C2.2, C6.2, C45.2, C46.2, C53.2, C54.2, J4.2, U2.2 (GND), U3.2 (GND), U3.3 (GND), U3.6 (GND), U3.7 (GND); also elsewhere on the board

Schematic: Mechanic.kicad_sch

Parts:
H1: MountingHole_Pad; MountingHole_2.5mm_Pad

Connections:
GND: H1.1; also elsewhere on the board

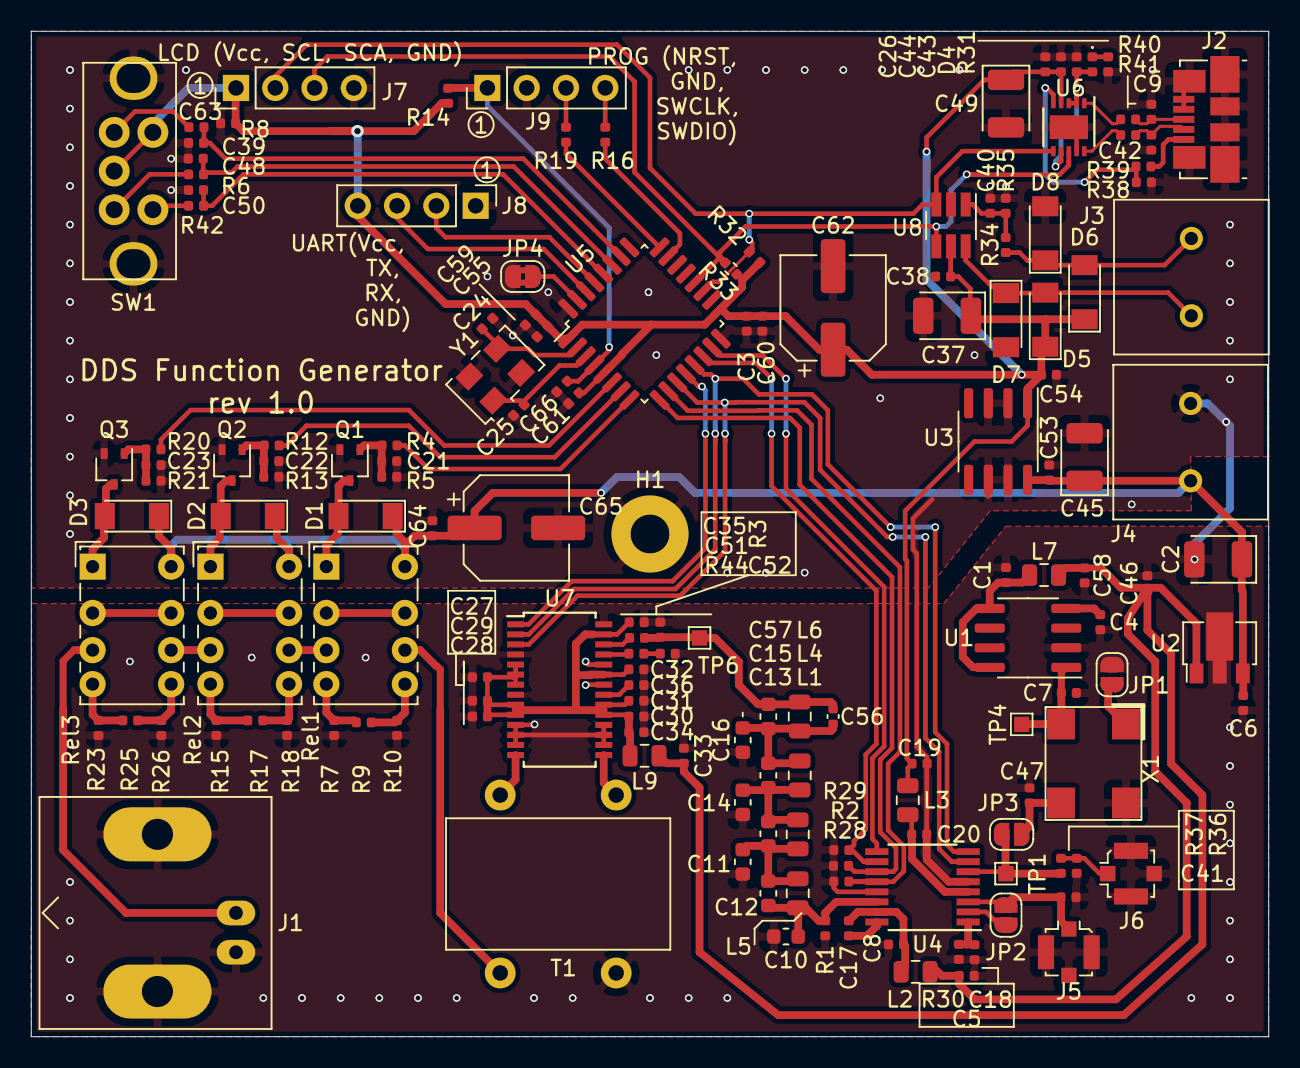
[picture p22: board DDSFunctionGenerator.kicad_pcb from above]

Board: 2 copper layers, 80.0 x 65.0 mm, 156 parts (0 on the bottom side), 86 nets.

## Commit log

2019-10-19 initial version
    [Amplifier.sch, Attenuators.sch, DDSRFGenerator.kicad_pcb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]
2019-10-19 draft of dds circuit
    [Attenuators.sch, ComputerInterface.sch, DDSRFGenerator.sch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]
2019-10-20 further draft
    [Amplifier.sch, Attenuators.sch, ComputerInterface.sch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]
2019-10-20 draft of correct relay connections
    [Attenuators.sch, DDSRFGenerator.kicad_pcb, DDSSynthesizer.sch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]
2019-10-20 rougly placed submodules on pcb
    [Attenuators.sch, ComputerInterface.sch, DDSRFGenerator.kicad_pcb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]
2019-10-26 files renamed after repo rename
    [Amplifier.sch, Attenuators.sch, ComputerInterface.sch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]
2019-10-26 draft of an amplifier
    [Amplifier.sch, Attenuators.sch, ComputerInterface.sch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]
2019-10-26 further refinement of amplifier
    [Amplifier.sch, DDSFunctionGenerator.kicad_pcb]
2019-10-27 modules placement improved
    [ADC.sch, Amplifier.sch, Attenuators.sch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]
2019-10-27 crystal generator footprint
2019-10-27 added osclilator 3d model
    [LF_SPXO018035.FCStd, LF_SPXO018035.scad, LF_SPXO018035.step]
2019-10-27 3d models added
    [Amplifier.sch, Attenuators.sch, BNC_Amphenol_B6252HB-NPP3G-50_Horizontal.FCStd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]
2019-11-01 added encoder 3d model
    [ADC.sch, Amplifier.sch, Attenuators.sch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]
2019-11-01 pcb more compact in size
2019-11-01 changed pcb size
    [ADC.sch, Amplifier.sch, Attenuators.sch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]
2019-11-02 update to recent kicad version
    [ADC.sch, Amplifier.sch, Attenuators.sch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]
2019-11-02 first routing
    [ADC.sch, Attenuators.sch, DDSFunctionGenerator.kicad_pcb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]
2019-11-02 before trying to remove "rescue" nonsense
    [DDSFunctionGenerator.kicad_pcb]
2019-11-02 it wasn't new kicad libs
    [ADC.sch, Amplifier.sch, Attenuators.sch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]
2019-11-03 further routing
    [ADC.sch, Amplifier.sch, Attenuators.sch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]
2019-11-03 model for adc/gpio socket
    [ADC.sch, Amplifier.sch, Attenuators.sch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]
2019-11-03 rf connector model
    [DG128-5.0-02P-14-00A.stl, MOLEX_73412-0110.FCStd, MOLEX_73412-0110.scad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]
2019-11-16 added missing components and connections
    [Amplifier.sch, Attenuators.sch, ComputerInterface.sch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]
2019-11-17 fix #31
    [Amplifier.sch, Microcontroller.sch]
2019-11-17 fix #27
    [Amplifier.sch, DDSFunctionGenerator.kicad_pcb]
2019-11-17 removed Vcc labels, use digital/analog ones
    [ADC.sch, ComputerInterface.sch, DDSFunctionGenerator.kicad_pcb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]
2019-11-17 rearangement of analog power
    [Amplifier.sch, DDSSynthesizer.sch, Microcontroller.sch]
2019-11-17 schematic drc pass
    [Amplifier.sch, Attenuators.sch, DDSSynthesizer.sch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]
2019-11-17 draft of pin usage
2019-11-20 added filter draft
2019-11-23 fixed filer coil footprint
    [DDSFunctionGenerator.kicad_pcb, DDSSynthesizer.sch]
2019-11-24 60dB eliptic filter
2019-11-24 updated dds filter
    [DDSFunctionGenerator.kicad_pcb, DDSSynthesizer.sch]
2019-11-24 redability improve
    [DDSSynthesizer.sch]
2019-11-24 pga imput fix for 50R single input
    [Amplifier.sch, DDSFunctionGenerator.kicad_pcb, DDSSynthesizer.sch]
2019-11-24 improved dds filter component placement
    [DDSFunctionGenerator.kicad_pcb]
2019-11-24 simplified attenuartors diagram
    [Attenuators.sch]
2019-11-28 redesign for analog/digital voltages trace
    [DDSFunctionGenerator.kicad_pcb]
2019-11-30 fixed schematic errors
    [ADC.sch, ComputerInterface.sch, UserInterface.sch]
2019-11-30 power supply connector
    [Microcontroller.sch]
2019-11-30 fixed cap value
    [Amplifier.sch]
2019-11-30 power supply draft for rf part
    [Amplifier.sch, DDSFunctionGenerator.kicad_pcb, DDSSynthesizer.sch]
2019-12-01 use smaller footprints
    [ADC.sch, Amplifier.sch, Attenuators.sch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]
2019-12-01 transformer model added
    [Amplifier.sch, DDSFunctionGenerator.kicad_pcb, Transformer_B62152_8.3.FCStd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]
2019-12-07 Fully routed RF part.
    [ADC.sch, Amplifier.sch, Attenuators.sch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]
2019-12-08 encoder footprint draft
    [DDSFunctionGenerator.kicad_pcb]
2019-12-08 added missing changes for encoder footprint
    [DDSFunctionGenerator.kicad_pcb, EN11-VNB1BQ15.FCStd, EN11-VNB1BQ15.step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]
2019-12-25 added BOM
2019-12-26 further bom simplification
    [ADC.sch, Amplifier.sch, ComputerInterface.sch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]
2019-12-26 further bom reduction
    [DDSSynthesizer.sch]
2019-12-26 mcu pinout fix
    [ADC.sch, Amplifier.sch, Attenuators.sch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]
2019-12-26 power supply moved to a separate sheet
    [ADC.sch, Amplifier.sch, Attenuators.sch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]
2019-12-26 minor improvements
    [DDSFunctionGenerator.kicad_pcb, DDSSynthesizer.sch, Microcontroller.sch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]
2019-12-27 further routing of mcu part
    [Attenuators.sch, DDSFunctionGenerator.kicad_pcb, Microcontroller.sch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]
2019-12-27 fixed vdd ground
    [DDSFunctionGenerator.kicad_pcb, Microcontroller.sch]
2019-12-28 routing completed
    [Amplifier.sch, Attenuators.sch, ComputerInterface.sch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]
2019-12-28 added vias on the corners
    [DDSFunctionGenerator.kicad_pcb]
2019-12-28 addded capacitors for filtering
    [Attenuators.sch]
2020-01-12 improved shape of gnd plane
    [DDSFunctionGenerator.kicad_pcb]
2020-05-24 draft of chassis (issue #50)
    [Chassis.FCStd, ChassisBottom.scad, DDSFunctionGenerator.kicad_pcb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]
2020-05-24 cut-off for srew connectors (issue #50)
    [Chassis.FCStd, ChassisBottom.scad]
2020-10-17 folder structure cleanup
    [ADC.sch, Amplifier.sch, Attenuators.sch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]
2020-10-18 transition to zForth
    [Chassis.FCStd, ChassisBottom.scad]
2026-02-07 pcb ready to be send to fabrication
    [ADC.kicad_sch, ADC.sch, Amplifier.kicad_sch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]
2026-02-07 modernize and cleanup the project
    [ADC.kicad_sch, Amplifier.kicad_sch, Attenuators.kicad_sch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]
